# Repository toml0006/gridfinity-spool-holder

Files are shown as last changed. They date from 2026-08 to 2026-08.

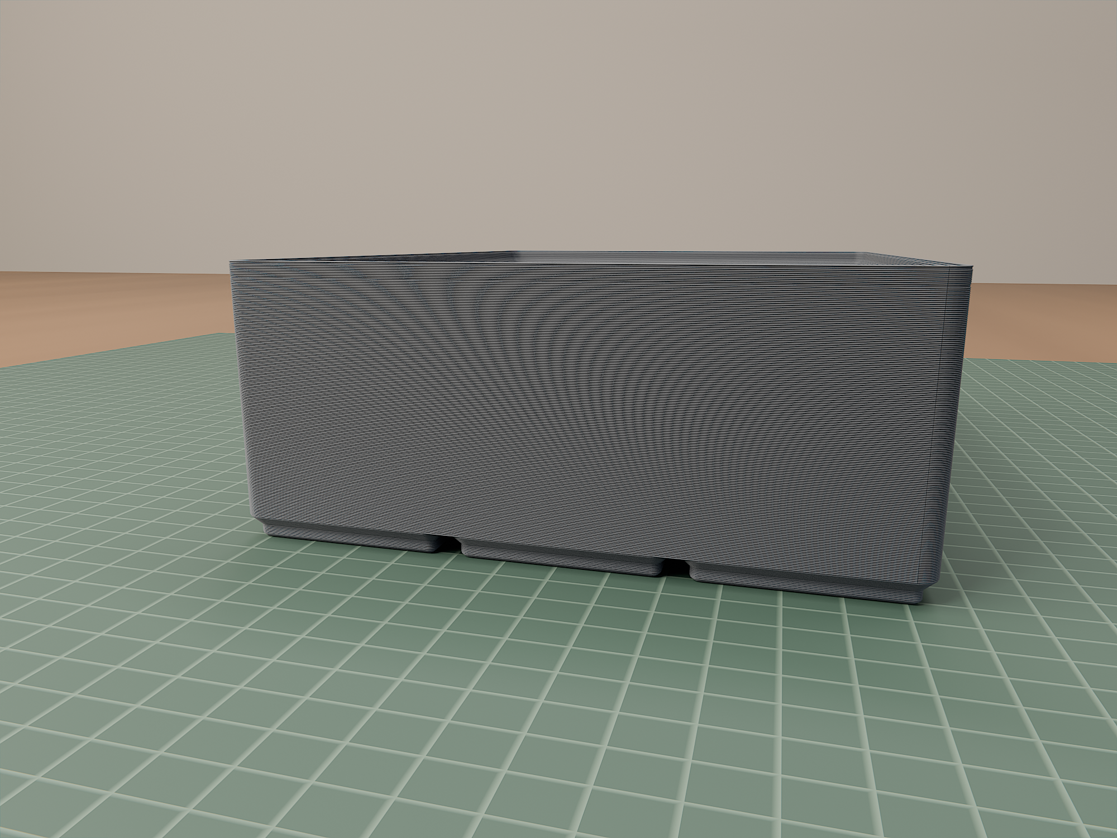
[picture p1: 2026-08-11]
renders/material_detail.png

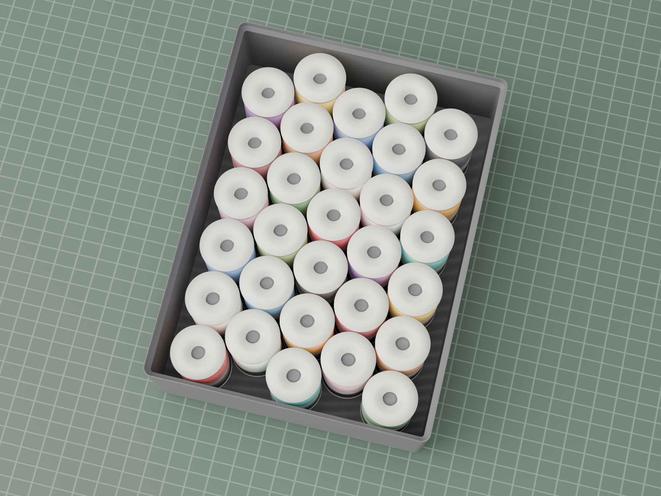
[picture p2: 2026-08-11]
renders/topdown_loaded.png

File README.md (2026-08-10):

# Gridfinity sewing thread spool holder

A stackable gridfinity bin with a hex-packed field of spool pegs.
3x4 cells, 7 height units, 30 spools.

```
make            # build the bin, validate it, build the test coupon
make bin        # out/spool_holder_3x4x7.stl
make coupon     # out/coupon_1x1.stl -- print this first
make validate   # measure the export against the spec
```

| | |
|---|---|
| Footprint | 125.5 x 167.5 mm (3 x 4 cells) |
| Height | 53.4 mm (7 units + 4.4 lip) |
| Stack pitch | 49.00 mm, exactly 7 per unit |
| Spools | 30 |
| Peg | dia 6.0, 38 mm proud of the floor, 0.75 chamfer |
| Modelled volume | 183 cm3 |

## Print the coupon first

`out/coupon_1x1.stl` is a 1x1 bin with a single peg, about ten minutes of
printing. It checks the three things that would otherwise waste a six hour
print: that the base seats in your baseplate, that the lip accepts another
bin, and that your spools actually fit the peg and the 24.68 mm spacing.

The lip is the one dimension not measured from a known-good local part --
see below -- so it is the thing most worth checking on a coupon.

## Where the numbers came from

Nothing here is recalled from memory. The base profile was measured off
`~/Documents/TomlinsonLTD/MakerWorld/Gridfinity/Calipers.3mf`, a bin known to
fit, by slicing it and fitting the geometry:

| Constant | Measured | How |
|---|---|---|
| Grid pitch | 42.0 | footprint / cell count |
| Outer footprint | 42n - 0.5 | 83.5 at 2 cells, 125.5 at 3 |
| Bottom inset | 3.20 / side | bottom span 77.60 at 2 cells |
| Chamfer angle | 45 deg | width grew 1.996 mm per mm |
| Base height | 4.75 | 0.8 + 1.8 + 2.15 |
| Corner radius | 3.75 top, 0.80 bottom | circle fit, error 0.0000 |
| Height convention | 7u + 3.8 lipless | 24.8 / 31.8 / 38.8 across 10 bins |

Cross-checked against `kennetek/gridfinity-rebuilt-openscad`, which agrees on
every one. Its `BASE_PROFILE_HEIGHT` reads 4.95, but its own segment lengths
(0.8 + 1.8 + 2.15) sum to 4.75 and the measured part is 4.75, so 4.75 is used.

### The lip is the unverified part

All ten local bins are lipless -- their outer wall runs dead straight from
the top of the base to the rim, so they seat in a baseplate but do not stack.
That left no local part to measure a stacking lip from, so the lip profile
(0.7 / 1.8 / 1.9, 4.4 tall) comes from the reference implementation only.

The rim inset is *derived* rather than taken: the bin above sinks until its
base flare jams against the rim, and that sink depth is the stack pitch.
Solving for a sink of exactly 4.4 gives a rim inset of 0.35, which puts the
pitch at exactly 49.00 mm for a 7 unit bin. `validate.py` recomputes this
from the exported mesh rather than trusting the constant.

## Peg layout

Derived from "2 large efficient Sewing Thread Spool Holder", measured off its
STLs: 23 pegs, dia 6.0, 38 mm proud of a 2 mm plate, chamfered tips, on a
lattice whose closest centre distance is 24.68 mm.

That 24.68 is the real constraint -- it is the widest a spool flange can be.
The original also spaced in-row neighbours 37.5 mm apart, which nothing
requires, so it spends 642 mm2 per spool where a true hex pack at the same
24.68 spacing spends 528. This model re-packs it properly: same clearances,
same spool compatibility, 30 spools instead of the 27 the original lattice
would tile into this footprint.

Columns run along Y. Running them the other way packs only 28.

## MakerWorld

`makerworld/gridfinity_spool_holder.scad` is a single self-contained file for
MakerWorld's Parametric Model Maker -- no `include<>` to resolve, and every
knob annotated for the customizer UI.

| Group | Parameters |
|---|---|
| Bin size | `grid_x`, `grid_y` (1-6 units), `grid_z` (3-20), `stacking_lip` |
| Spools | `spool_spacing`, `peg_dia`, `peg_height` |
| Shell | `wall`, `floor_thickness` |
| Quality | `detail` |

Footprint is capped at 6 units because 6 x 42 - 0.5 = 251.5mm, about as much
as a 256mm bed takes. `detail` is the escape hatch if generation times out:
it is facets per circle, and render time is close to linear in it.

Rendered locally on OpenSCAD 2021.01, which is CGAL only. Anything newer uses
the Manifold backend and is far quicker, so treat these as a pessimistic
ceiling rather than what MakerWorld will do:

| Case | Pegs | Render |
|---|---|---|
| 1x1x3 | 1 | 8s |
| 2x3x7 | 12 | 17s |
| 3x4x7 default | 30 | 25s |
| spacing 15 | 90 | 82s |
| 6x6x7 | 105 | 104s |

Every one of eleven cases across the parameter range -- the extremes of each
range, lipless, dense and sparse spacing, fat pegs, thick walls -- renders to
a watertight single body with positive volume. The default configuration also
passes all 33 geometry checks in `validate.py`.

Two things worth knowing if you edit it. Sections of the base and lip meet on
exact planes, and solids that only touch on a coincident face are not
reliably fused -- the result measures perfectly and is not watertight, so it
will not slice. The straight sections are deliberately grown 0.01mm into
their neighbours to prevent that. And rounded boxes are built as a hull of
four cylinders rather than `offset()` on a square: both are exact, but
`offset()` is a 2D minkowski and costs far more.

## Fusion 360

`fusion/GridfinitySpoolHolder.py` builds the same bin through the Fusion API.
Install it under `API/Scripts/GridfinitySpoolHolder/` and run it from
Utilities > Scripts and Add-Ins.

It opens a dialog first, seeded from the design's user parameters if they
exist and from the defaults in the file otherwise. Nothing is built and
nothing is deleted until you press OK. Pressing OK writes the values back to
the design, so the file, the dialog and the parameters stay in step. Set
`ASK_BEFORE_RUN = False` to skip the dialog for scripted runs.

**Changing a parameter does not rebuild the model on its own -- run the
script again.** That is a genuine limit rather than an oversight: the unit
counts and the spool spacing change how many feet and pegs exist, and a
parameter cannot add or remove bodies. Re-running is safe and repeatable,
because the script deletes the previous build first.

Deleting that previous build is fiddly enough to be worth recording. Deleting
the sketches does *not* cascade to the features that consumed them, and
calling `deleteMe()` on a body returns `True` while leaving the body in
place. Clearing anything other than the features first appears to work and
silently leaves the old bin behind, renamed to `Body2`, sitting inside the
new one. The features have to go first, newest to oldest.

| Parameter | Meaning |
|---|---|
| `gf_units_x` / `gf_units_y` | footprint, in 42mm gridfinity units |
| `gf_units_z` | height, in 7mm units |
| `spool_spacing` | peg centre spacing, and the widest flange that fits |
| `peg_height` / `peg_dia` | peg size |
| `wall` / `floor_thickness` | shell |

Peg count follows from the footprint and spacing; the lattice re-packs and
re-centres itself. Below 7 height units a 38mm peg stands proud of the rim
and the bin stops stacking, so the script warns and tells you the minimum.

The whole part is 11 features. Every peg circle shares one sketch and the
whole collection of profiles goes into a single extrude, and the base is one
foot plus a rectangular pattern. Extruding each profile separately instead
built the identical part out of 165 features and a 219 entry timeline.

## Known tradeoffs

- The base feet are modelled solid. Real gridfinity libraries hollow them to
  save material; here the slicer's infill does that job. If you want the
  filament back, hollowing the feet is the place to look.
- Wall is 1.6 mm, thicker than the 0.95 the reference uses, because the peg
  field puts spool loads on the walls.
- No label tab, no scoop. The pegs need the floor area more.

## Files

- `gridfinity.scad` -- base profile, stacking lip, bin shell. No spool logic,
  reusable for the next bin.
- `spool_holder.scad` -- peg lattice and assembly. Parameters at the top.
- `validate.py` -- measures an exported STL against the spec. 33 checks.

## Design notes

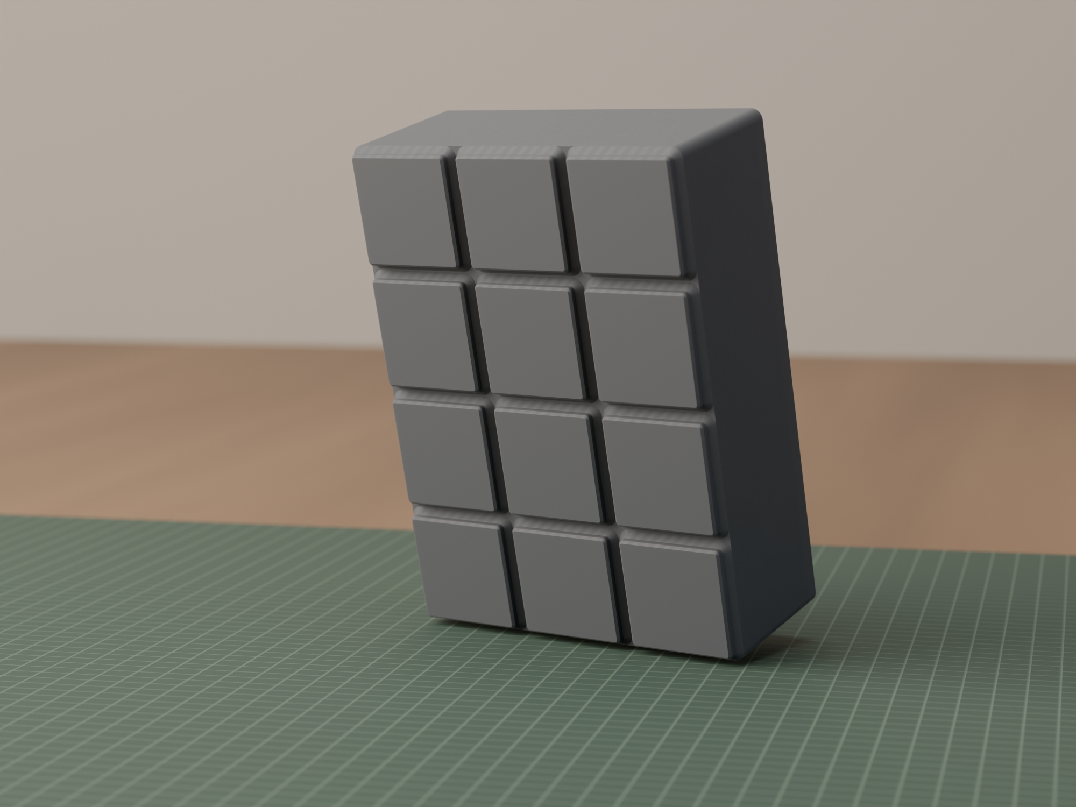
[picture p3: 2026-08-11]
renders/macro_base_lip.png

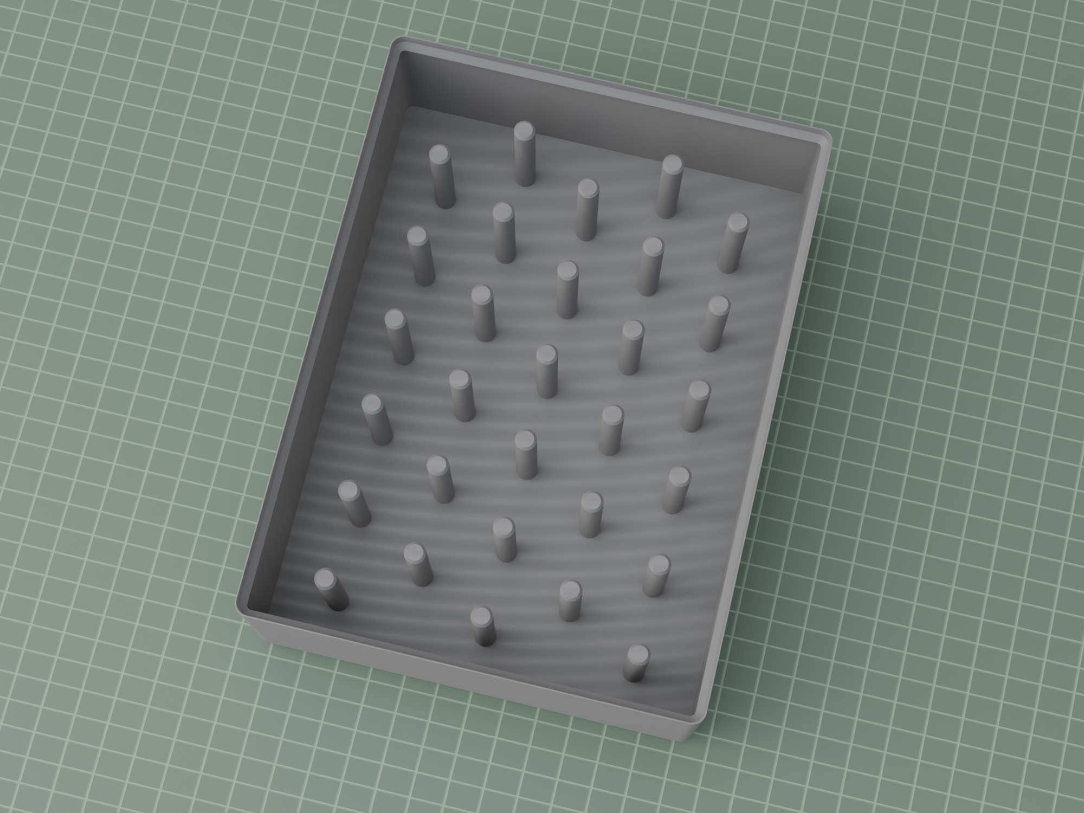
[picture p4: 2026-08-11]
renders/topdown_empty.png

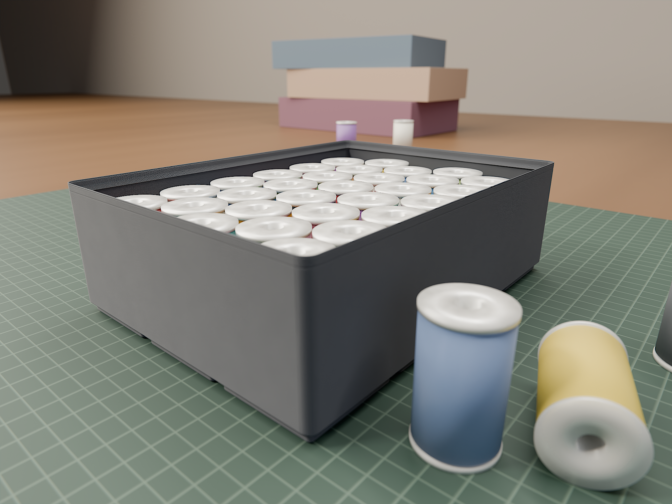
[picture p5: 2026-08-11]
renders/hero_loaded.png

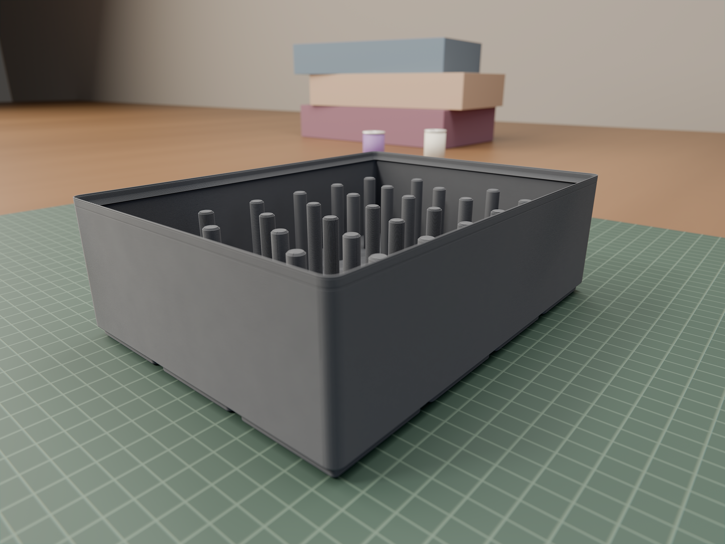
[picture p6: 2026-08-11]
renders/hero_empty.png

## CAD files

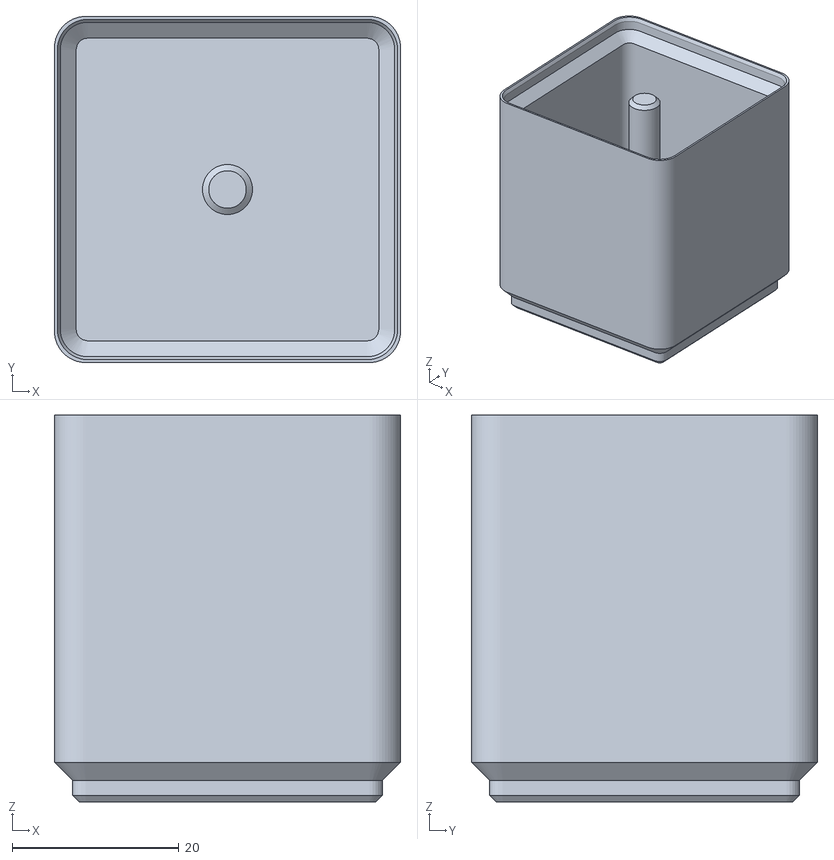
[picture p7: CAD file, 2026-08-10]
out/coupon_1x1.stl
41.5 x 41.5 x 46.4

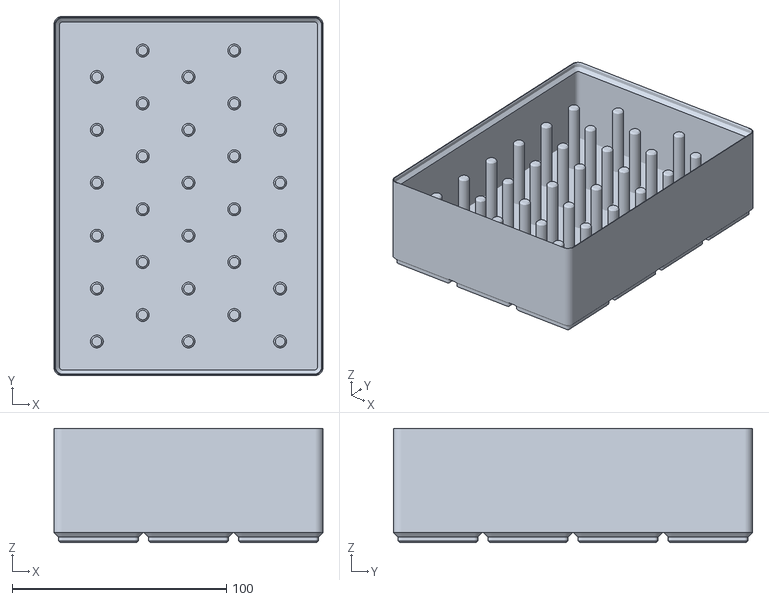
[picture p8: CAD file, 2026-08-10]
out/spool_holder_3x4x7.stl
125.5 x 167.5 x 53.4

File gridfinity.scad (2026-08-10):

// Gridfinity primitives.
//
// Every constant below was measured off a known-good bin
// (Documents/TomlinsonLTD/MakerWorld/Gridfinity/Calipers.3mf) rather than
// recalled, then cross-checked against kennetek/gridfinity-rebuilt-openscad.
// See README.md for the measurements and the one place the two disagree.

GF_PITCH      = 42;     // grid pitch
GF_GAP        = 0.5;    // outer footprint is PITCH*n - GAP
GF_TOP_INSET  = 0.25;   // = GAP/2, inset per side at top of base
GF_R_TOP      = 3.75;   // corner radius at top of base and up the wall

// Base profile, bottom to top. Insets are per side, measured in from the
// nominal 42mm cell edge. Bottom inset 3.20 = 0.25 + 0.8 + 2.15.
GF_BASE_C1    = 0.8;    // lower 45 deg chamfer
GF_BASE_STR   = 1.8;    // vertical section
GF_BASE_C2    = 2.15;   // upper 45 deg chamfer
GF_BASE_H     = GF_BASE_C1 + GF_BASE_STR + GF_BASE_C2;   // 4.75
GF_BOT_INSET  = GF_TOP_INSET + GF_BASE_C1 + GF_BASE_C2;  // 3.20

// Stacking lip. Insets are per side, in from the outer wall.
//
// The lip is a funnel that opens towards the rim: widest at the top so the
// feet of the bin above can drop in, narrowing to an inward ledge at the
// bottom of the lip which is what actually takes the load. Build it the
// other way up and the wall cavity just swallows it.
GF_LIP_C1     = 0.7;    // 45 deg at the rim, and the throat inset
GF_LIP_STR    = 1.8;    // vertical throat
GF_LIP_C2     = 1.9;    // 45 deg down to the ledge
GF_LIP_H      = GF_LIP_C1 + GF_LIP_STR + GF_LIP_C2;      // 4.40
GF_LIP_W      = GF_LIP_C1 + GF_LIP_C2;                   // 2.60, ledge inset
// Spec puts the rim at zero inset, i.e. a knife edge. Back it off so the rim
// prints as a real surface -- but the amount is derived, not chosen. The bin
// above sinks until its base flare jams on the rim, and that sink depth sets
// the stack pitch. Make it jam at exactly GF_LIP_H and the pitch comes out at
// exactly GF_UNIT_Z per height unit, so a tall stack stays on the grid.
//
// So the rim inset is however much wider the outer wall is than the base at
// GF_LIP_H above its underside: 0.60 - 0.25 = 0.35.
function gf_base_inset(t) =
      t <= GF_BASE_C1               ? GF_BOT_INSET - t
    : t <= GF_BASE_C1 + GF_BASE_STR ? GF_BOT_INSET - GF_BASE_C1
    : max(GF_TOP_INSET, GF_BOT_INSET - GF_BASE_C1 - (t - GF_BASE_C1 - GF_BASE_STR));

GF_LIP_TIP    = gf_base_inset(GF_LIP_H) - GF_TOP_INSET;   // 0.35

GF_UNIT_Z     = 7;      // height unit
GF_Z_LIPLESS  = 3.8;    // total = 7*u + this, for a lipless bin

// Corner radius shrinks 1:1 with inset, so the whole base is one rounded
// rect swept through a varying offset. Falls out of the measurements:
// at inset 3.20 this gives 0.80, and 0.80 is what the bottom face measures.
function gf_radius(inset) = GF_R_TOP - (inset - GF_TOP_INSET);

function gf_outer(n) = GF_PITCH * n - GF_GAP;

// Total outer height of a bin.
function gf_height(zu, lip = true) =
    GF_UNIT_Z * zu + (lip ? GF_LIP_H : GF_Z_LIPLESS);

// Rounded rectangular prism, centered in X/Y, sitting on z=0.
module gf_rrect(sx, sy, r, h) {
    linear_extrude(height = h)
        offset(r = r)
            square([sx - 2*r, sy - 2*r], center = true);
}

// A rounded rect described by its inset from a footprint, so radius stays
// consistent with the profile.
module gf_rrect_inset(fx, fy, inset, h) {
    gf_rrect(fx - 2*inset, fy - 2*inset, gf_radius(inset), h);
}

// One base foot, occupying a single 42mm cell, sitting on z=0.
module gf_foot(eps = 0.002) {
    P = GF_PITCH;
    // 45 deg run-out from the bottom inset to the straight section
    hull() {
        gf_rrect_inset(P, P, GF_BOT_INSET, eps);
        translate([0, 0, GF_BASE_C1 - eps])
            gf_rrect_inset(P, P, GF_BOT_INSET - GF_BASE_C1, eps);
    }
    // straight section
    translate([0, 0, GF_BASE_C1])
        gf_rrect_inset(P, P, GF_BOT_INSET - GF_BASE_C1, GF_BASE_STR);
    // 45 deg flare out to full width at the top of the base
    hull() {
        translate([0, 0, GF_BASE_C1 + GF_BASE_STR])
            gf_rrect_inset(P, P, GF_BOT_INSET - GF_BASE_C1, eps);
        translate([0, 0, GF_BASE_H - eps])
            gf_rrect_inset(P, P, GF_TOP_INSET, eps);
    }
}

// Full base: one foot per cell, arrayed on the grid. The 0.5mm grooves
// between adjacent feet are intentional and are what the grid looks like.
module gf_base(gx, gy) {
    for (i = [0:gx-1], j = [0:gy-1])
        translate([(i - (gx-1)/2) * GF_PITCH,
                   (j - (gy-1)/2) * GF_PITCH, 0])
            gf_foot();
}

// Solid outer body from the top of the base up to `h`.
module gf_body(gx, gy, h) {
    translate([0, 0, GF_BASE_H])
        gf_rrect(gf_outer(gx), gf_outer(gy), GF_R_TOP, h - GF_BASE_H);
}

// Negative for the stacking lip: the socket cut into the rim that receives
// the feet of the bin above. Cut from the ledge upward, widening as it goes.
module gf_lip_negative(gx, gy, h, eps = 0.002) {
    fx = gf_outer(gx);
    fy = gf_outer(gy);
    throat_z = h - GF_LIP_C1 - GF_LIP_STR;
    // ledge at the bottom of the lip, opening out to the throat
    hull() {
        translate([0, 0, h - GF_LIP_H])
            gf_rrect_inset(fx, fy, GF_LIP_W, eps);
        translate([0, 0, throat_z])
            gf_rrect_inset(fx, fy, GF_LIP_C1, eps);
    }
    // vertical throat
    translate([0, 0, throat_z])
        gf_rrect_inset(fx, fy, GF_LIP_C1, GF_LIP_STR);
    // final flare out to the rim
    hull() {
        translate([0, 0, h - GF_LIP_C1])
            gf_rrect_inset(fx, fy, GF_LIP_C1, eps);
        translate([0, 0, h - eps])
            gf_rrect_inset(fx, fy, GF_LIP_TIP, eps);
    }
    // everything above the rim is open
    translate([0, 0, h - eps])
        gf_rrect_inset(fx, fy, GF_LIP_TIP, GF_LIP_H);
}

// An open bin: base, walls, cavity, optional stacking lip.
// The cavity floor sits at z = GF_BASE_H + floor_h.
module gf_bin(gx, gy, zu, wall = 1.6, floor_h = 1.25, lip = true) {
    h = gf_height(zu, lip);
    difference() {
        union() {
            gf_base(gx, gy);
            gf_body(gx, gy, h);
        }
        // Interior cavity. It has to stop at the bottom of the lip, otherwise
        // it cuts straight through and erases the ledge -- the wall is
        // thinner than the ledge inset, so whichever cut runs deeper wins.
        cavity_top = lip ? h - GF_LIP_H : h;
        floor_z = GF_BASE_H + floor_h;
        translate([0, 0, floor_z])
            gf_rrect(gf_outer(gx) - 2*wall, gf_outer(gy) - 2*wall,
                     max(0.1, GF_R_TOP - wall), cavity_top - floor_z);
        if (lip) gf_lip_negative(gx, gy, h);
    }
}

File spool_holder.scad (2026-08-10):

// Gridfinity sewing thread spool holder.
//
// Derived from "2 large efficient Sewing Thread Spool Holder", whose peg
// geometry was measured directly off its STLs: 23 pegs, dia 6.0, 38mm proud
// of a 2mm plate, with a lead-in chamfer at the tip, on a lattice whose
// closest center-to-center distance is 24.68mm.
//
// That 24.68 is the real constraint -- it is the widest a spool flange can
// be. The original lattice also spaced in-row neighbours 37.5mm apart, which
// is pure slack, so this version re-packs the same spacing as a true hex
// grid. Same clearances, more spools.

include <gridfinity.scad>

/* [Grid] */
GRID_X       = 3;      // cells in X
GRID_Y       = 4;      // cells in Y
GRID_Z       = 7;      // height units (7mm each)
STACKING_LIP = true;   // false matches the rest of the library, but won't stack

/* [Shell] */
WALL         = 1.6;    // side wall thickness
FLOOR        = 1.25;   // floor above the top of the gridfinity base

/* [Spools] */
SPOOL_DIA    = 24.68;  // widest spool flange = min peg center distance
PEG_DIA      = 6.0;    // spool bore is ~6.3
PEG_H        = 38.0;   // proud of the floor
PEG_CHAMFER  = 0.75;   // lead-in at the tip

/* [Output] */
PART         = "bin";  // "bin" or "coupon"

$fa = 1;
$fs = 0.4;

// ---------------------------------------------------------------------------
// Peg lattice
//
// Columns run along Y so the long axis of the bin gets the tighter spacing.
// For a 3x4 that packs 30 pegs; running them the other way packs only 28.
// ---------------------------------------------------------------------------

function col_spacing() = SPOOL_DIA * sqrt(3) / 2;

// Usable span for peg *centers*: interior minus half a spool at each edge.
function span_x(gx) = gf_outer(gx) - 2*WALL - SPOOL_DIA;
function span_y(gy) = gf_outer(gy) - 2*WALL - SPOOL_DIA;

function n_cols(gx) = floor(span_x(gx) / col_spacing()) + 1;
function col_offset(j) = (j % 2 == 1) ? SPOOL_DIA/2 : 0;
function n_in_col(gy, j) = floor((span_y(gy) - col_offset(j)) / SPOOL_DIA) + 1;

function peg_grid(gx, gy) = [
    for (j = [0 : n_cols(gx) - 1], i = [0 : n_in_col(gy, j) - 1])
        [ j * col_spacing(), col_offset(j) + i * SPOOL_DIA ]
];

// Center the generated pattern in the interior rather than assuming it is
// symmetric -- offset columns end at a different Y than even ones.
function grid_extent(pts, axis) =
    max([for (p = pts) p[axis]]) - min([for (p = pts) p[axis]]);

module peg() {
    straight = PEG_H - PEG_CHAMFER;
    cylinder(h = straight, d = PEG_DIA);
    translate([0, 0, straight])
        cylinder(h = PEG_CHAMFER, d1 = PEG_DIA, d2 = PEG_DIA - 2*PEG_CHAMFER);
}

module peg_field(gx, gy) {
    pts = peg_grid(gx, gy);
    ox = -grid_extent(pts, 0) / 2;
    oy = -grid_extent(pts, 1) / 2;
    for (p = pts) translate([p[0] + ox, p[1] + oy, 0]) peg();
}

// ---------------------------------------------------------------------------
// Assembly
// ---------------------------------------------------------------------------

module spool_bin(gx, gy, zu) {
    union() {
        gf_bin(gx, gy, zu, WALL, FLOOR, STACKING_LIP);
        translate([0, 0, GF_BASE_H + FLOOR]) peg_field(gx, gy);
    }
}

// A 1x1 test print: checks baseplate fit, lip fit and spool fit for the cost
// of a few minutes, before committing to the full bin.
module coupon() {
    union() {
        gf_bin(1, 1, 6, WALL, FLOOR, STACKING_LIP);
        translate([0, 0, GF_BASE_H + FLOOR]) peg();
    }
}

if (PART == "coupon") coupon();
else spool_bin(GRID_X, GRID_Y, GRID_Z);

echo(str("pegs = ", len(peg_grid(GRID_X, GRID_Y))));
echo(str("outer = ", gf_outer(GRID_X), " x ", gf_outer(GRID_Y),
         " x ", gf_height(GRID_Z, STACKING_LIP)));

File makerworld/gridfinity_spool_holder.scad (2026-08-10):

/*
 * Gridfinity sewing thread spool holder -- parametric.
 *
 * A stackable gridfinity bin whose floor is a hex packed field of pegs, one
 * spool per peg. Set the footprint in gridfinity units and the spacing to
 * suit your spools; the peg field re-packs and re-centres itself.
 *
 * Single file on purpose: MakerWorld's Parametric Model Maker runs one
 * script, so there are no include<> statements to resolve.
 *
 * Every gridfinity constant here was measured off a bin known to fit rather
 * than recalled. Source and validator:
 * https://github.com/toml0006/gridfinity-spool-holder
 */

/* [Bin size] */

// Width, in gridfinity units of 42mm. 6 units is 251.5mm, about as much as a 256mm bed takes
grid_x = 3;         // [1:6]
// Depth, in gridfinity units of 42mm
grid_y = 4;         // [1:6]
// Height, in units of 7mm. Below 7 a 38mm peg stands proud of the rim and the bin stops stacking
grid_z = 7;         // [3:20]
// Stacking lip. Turn off to match a lipless library: still seats in a baseplate, but will not stack
stacking_lip = true;

/* [Spools] */

// Centre to centre spacing. This is the widest spool flange that will fit
spool_spacing = 24.68;  // [15:0.01:60]
// Peg diameter. Typical spool bore is about 6.3mm
peg_dia = 6;        // [3:0.1:12]
// How far the peg stands above the floor
peg_height = 38;    // [10:1:80]

/* [Shell] */

// Side wall thickness
wall = 1.6;         // [0.8:0.1:4]
// Floor above the top of the gridfinity base
floor_thickness = 1.25;  // [0.8:0.05:4]

/* [Quality] */

// Facets per full circle. Raise for a smoother finish, lower if generating times out
detail = 20;        // [12:4:48]

/* [Hidden] */

// --------------------------------------------------------------------------
// Gridfinity constants. Measured, not tuned.
//
//   pitch 42, outer footprint 42n - 0.5, corner radius 3.75 at the top of the
//   base falling to 0.80 at the bottom face, base profile 0.8 chamfer / 1.8
//   straight / 2.15 chamfer = 4.75 tall, both chamfers at 45 degrees.
// --------------------------------------------------------------------------

PITCH      = 42;
GAP        = 0.5;
TOP_INSET  = GAP / 2;                       // 0.25
R_TOP      = 3.75;

BASE_C1    = 0.8;                           // lower 45 deg chamfer
BASE_STR   = 1.8;                           // vertical section
BASE_C2    = 2.15;                          // upper 45 deg chamfer
BASE_H     = BASE_C1 + BASE_STR + BASE_C2;  // 4.75
BOT_INSET  = TOP_INSET + BASE_C1 + BASE_C2; // 3.20

UNIT_Z     = 7;
Z_LIPLESS  = 3.8;

// Stacking lip: a funnel that opens towards the rim. Widest at the top so the
// feet of the bin above drop in, narrowing to an inward ledge at the bottom
// which is what takes the load. Built the other way up, the wall cavity just
// swallows it and there is no lip at all.
LIP_C1     = 0.7;                           // throat inset, and the rim chamfer
LIP_STR    = 1.8;                           // vertical throat
LIP_C2     = 1.9;                           // 45 deg down to the ledge
LIP_H      = LIP_C1 + LIP_STR + LIP_C2;     // 4.40
LIP_W      = LIP_C1 + LIP_C2;               // 2.60, ledge inset

PEG_CHAMFER = 0.75;                         // lead-in at the peg tip
EPS         = 0.01;

// Sections of the base and the lip meet on exact planes. Solids that only
// touch on a coincident face are not reliably fused, and the result is a
// shell that measures correctly but is not watertight, so it will not slice.
// Straight sections are grown by this much into their neighbours to give the
// union real volume to work with. It is below one print layer.
OVER = 0.01;

// Inset per side of a base, t mm above its underside.
function base_inset(t) =
      t <= BASE_C1             ? BOT_INSET - t
    : t <= BASE_C1 + BASE_STR  ? BOT_INSET - BASE_C1
    : max(TOP_INSET, BOT_INSET - BASE_C1 - (t - BASE_C1 - BASE_STR));

// The bin above sinks until its base flare jams on the rim, and that depth is
// the stack pitch. Seating at exactly LIP_H makes the pitch exactly UNIT_Z per
// height unit, which is what keeps a tall stack on the grid.
LIP_TIP = base_inset(LIP_H) - TOP_INSET;    // 0.35

function outer(n)  = PITCH * n - GAP;
function radius_for(inset) = max(0.01, R_TOP - (inset - TOP_INSET));
function total_height() = UNIT_Z * grid_z + (stacking_lip ? LIP_H : Z_LIPLESS);

// --------------------------------------------------------------------------
// Primitives
//
// Rounded boxes are built as a hull of four cylinders rather than
// offset() on a square. Both are exact, but offset() is a 2D minkowski and
// costs far more; on a 3x4 bin the cylinder form renders many times faster,
// which matters when the generator has a wall-clock budget.
// --------------------------------------------------------------------------

module rbox(sx, sy, r, h) {
    rr = max(0.01, min(r, min(sx, sy) / 2 - 0.001));
    hull()
        for (dx = [-1, 1], dy = [-1, 1])
            translate([dx * (sx / 2 - rr), dy * (sy / 2 - rr), 0])
                cylinder(h = max(h, EPS), r = rr, $fn = detail);
}

// Rounded box described by its inset from a footprint, so the corner radius
// stays consistent with the base profile.
module rbox_inset(fx, fy, inset, h) {
    rbox(fx - 2 * inset, fy - 2 * inset, radius_for(inset), h);
}

// A 45 degree run between two insets, as a single hull of eight cylinders.
module taper(fx, fy, z0, inset0, z1, inset1) {
    hull() {
        translate([0, 0, z0]) rbox_inset(fx, fy, inset0, EPS);
        translate([0, 0, z1 - EPS]) rbox_inset(fx, fy, inset1, EPS);
    }
}

// --------------------------------------------------------------------------
// Base
// --------------------------------------------------------------------------

// One foot, occupying a single 42mm cell.
module foot() {
    taper(PITCH, PITCH, 0, BOT_INSET, BASE_C1, BOT_INSET - BASE_C1);
    translate([0, 0, BASE_C1 - OVER])
        rbox_inset(PITCH, PITCH, BOT_INSET - BASE_C1, BASE_STR + 2 * OVER);
    taper(PITCH, PITCH, BASE_C1 + BASE_STR, BOT_INSET - BASE_C1,
          BASE_H, TOP_INSET);
}

// The 0.5mm grooves between adjacent feet are intentional; that is what the
// underside of a gridfinity bin looks like.
module base() {
    for (i = [0 : grid_x - 1], j = [0 : grid_y - 1])
        translate([(i - (grid_x - 1) / 2) * PITCH,
                   (j - (grid_y - 1) / 2) * PITCH, 0])
            foot();
}

// --------------------------------------------------------------------------
// Peg lattice
// --------------------------------------------------------------------------

// Hex packed with columns running along Y. The spacing is the only real
// constraint: it is the widest a spool flange can be. Columns along Y pack 30
// pegs into a 3x4; running them the other way packs only 28.
function col_spacing() = spool_spacing * sqrt(3) / 2;
function span_x() = outer(grid_x) - 2 * wall - spool_spacing;
function span_y() = outer(grid_y) - 2 * wall - spool_spacing;
function n_cols()  = span_x() < 0 ? 0 : floor(span_x() / col_spacing()) + 1;
function col_off(j) = (j % 2 == 1) ? spool_spacing / 2 : 0;
function n_in_col(j) = span_y() < col_off(j) ? 0
                     : floor((span_y() - col_off(j)) / spool_spacing) + 1;

function peg_grid() = [
    for (j = [0 : max(0, n_cols() - 1)], i = [0 : max(0, n_in_col(j) - 1)])
        if (n_cols() > 0 && n_in_col(j) > 0)
            [j * col_spacing(), col_off(j) + i * spool_spacing]
];

// Offset columns end at a different Y than even ones, so the generated block
// is not symmetric about its own origin and has to be centred explicitly.
function grid_mid(pts, axis) =
    (min([for (p = pts) p[axis]]) + max([for (p = pts) p[axis]])) / 2;

// Revolved as one solid rather than a shaft plus a cone. Two primitives per
// peg means twice the solids for the final union to chew through, and with
// thirty pegs that is the single biggest cost in the script.
module peg() {
    r = peg_dia / 2;
    r_tip = max(0.05, r - PEG_CHAMFER);
    straight = peg_height - PEG_CHAMFER;
    // Sunk OVER into the floor for the same reason the base sections overlap.
    rotate_extrude($fn = detail)
        polygon([[0, -OVER], [r, -OVER], [r, straight],
                 [r_tip, peg_height], [0, peg_height]]);
}

module peg_field() {
    pts = peg_grid();
    if (len(pts) > 0) {
        ox = grid_mid(pts, 0);
        oy = grid_mid(pts, 1);
        for (p = pts) translate([p[0] - ox, p[1] - oy, 0]) peg();
    }
}

// --------------------------------------------------------------------------
// Assembly
// --------------------------------------------------------------------------

module lip_negative(fx, fy, h) {
    throat_z = h - LIP_C1 - LIP_STR;
    taper(fx, fy, h - LIP_H, LIP_W, throat_z, LIP_C1);
    translate([0, 0, throat_z - OVER])
        rbox_inset(fx, fy, LIP_C1, LIP_STR + 2 * OVER);
    taper(fx, fy, h - LIP_C1, LIP_C1, h, LIP_TIP);
    translate([0, 0, h - EPS]) rbox_inset(fx, fy, LIP_TIP, LIP_H);
}
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

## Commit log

2026-08-10 Add gridfinity spool holder, 3x4x7 with 30 hex-packed pegs
    Regenerates the "2 large efficient Sewing Thread Spool Holder" as a native
    gridfinity bin rather than wrapping the original 100x150 print in a sleeve.
    The base profile is measured off a known-good local bin (Calipers.3mf) rather
    than recalled: 42 pitch, 42n-0.5 footprint, 0.8/1.8/2.15 base at 45 degrees,
    3.75 corner radius. Cross-checked against gridfinity-rebuilt-openscad, which
    agrees on every constant.
    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
    [coupon_1x1.stl, gridfinity.scad, spool_holder.scad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]
2026-08-10 Add Fusion 360 script, verified against the same 33 checks
    Generates the same bin through the Fusion API instead of OpenSCAD, driven by
    gridfinity unit counts for width, depth and height plus spool spacing and peg
    height. Mirrors the inputs into user parameters so they are visible in the UI.
    Built in a live Fusion session over the local MCP server, exported to STL and
    run through validate.py: 33/33, identical numbers to the OpenSCAD build, and
    volume agrees to 182.99 vs 182.9 cm3. Two independent implementations landing
    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
2026-08-10 Make the Fusion parameters actually drive the model
    The user parameters were decorative. Every extrude distance was a literal and
    every sketch had zero dimensions and zero constraints, so nothing in 175
    timeline features referenced a parameter -- editing gf_units_x to 2 left a
    125.5mm body on screen.
    The script now reads the parameters back out of the design and rebuilds, so
    editing them in Modify > Change Parameters and re-running produces the right
    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
2026-08-10 Prompt before building, and cut 165 features down to 11
    Two problems, both mine.
    The script built and deleted immediately on launch. It now opens a dialog
    seeded from the design parameters, so nothing is touched until you press OK,
    and the values you set are written back to the design. ASK_BEFORE_RUN = False
    skips it for scripted runs.
    The operations were also unbatched to the point of absurdity: every peg got
    its own extrude and every foot got three, so a part that needs about a dozen
    features was built from 165 with a 219 entry timeline. Every peg circle now
    shares one sketch and the whole profile collection goes into a single
    extrude, and the base is one foot plus a rectangular pattern.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
2026-08-10 Add a single-file parametric model for MakerWorld
    MakerWorld's Parametric Model Maker runs one script, so gridfinity.scad and
    spool_holder.scad are inlined into makerworld/gridfinity_spool_holder.scad
    with customizer annotations on every parameter.
    Footprint is capped at 6 units because 6*42-0.5 is 251.5mm, about as much as
    a 256mm bed takes, and detail is exposed as the escape hatch if generation
    times out.
    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
    [gridfinity_spool_holder.scad]
2026-08-10 Add studio renders and the script that produces them
    Six shots for a model listing: hero empty and loaded, a stacked pair, the peg
    field from above empty and loaded, and the underside showing the gridfinity
    feet.
    Scenes are assembled at 1 unit = 1 metre and lit in watts, so falloff, shadow
    softness and depth of field fall out of physical numbers. That also means the
    light values look surprisingly small: the first pass used 900W softboxes and
    blew a 0.055 albedo to near white.
    Spools are generated rather than modelled, revolved from a profile at the
    dimensions the 24.68mm peg spacing permits, so what sits in the bin is what
    actually fits. The stacked shot separates the bins by exactly 49.00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
2026-08-11 Fix parts sinking into the ground, and move the renders to a craft room
    The bin's underside sits at exactly z=0 and so did the table, and two
    coplanar faces z-fight: the renderer let the ground cut through the feet, so
    every shot had the part sunk into the floor. Anything resting on a surface is
    now lifted 0.15mm, which is sub-visible and enough. Verified by measuring the
    imported mesh rather than by eye, which is how it got shipped the first time.
    The filament shader was one texture applied everywhere. A print shows layer
    lines on its walls and extrusion beads on its top faces, at different pitches
    and directions, and using layer lines on a top surface is most of what made
    this read as CAD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
2026-08-11 Fix the filament shader: texture space was 1000x off
    The layer lines never worked, and lighting and profile tuning were never
    going to fix it. stl_import(global_scale) sets object.scale and leaves the
    mesh in millimetres, but object-space texture coordinates read mesh-local
    values. The shader was seeing a part 53 units tall instead of 0.053, so a
    pitch computed from the real 0.2mm layer height asked for a period of
    0.0002mm and aliased into noise. That was the corduroy on the corner shot and
    the flat grey head on. Scale is now applied at import so local space is
    metres like everything else.
    With the space right, the profile matters. A bead is not a sine wave: it
    leaves the nozzle round, get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
2026-08-11 Rework the filament shader on external research
    Asked Codex (gpt-5.6-sol, high effort) to research state of the art FDM
    rendering. Its diagnosis: the shader over-describes layer relief and
    under-describes the manufacturing path, and a perfectly periodic arc repeated
    every 0.20mm with matching roughness and AO is almost exactly how you get "CG
    plastic with stripes".
    Applied, in its priority order:
    Decorrelated the signals. Displacement, roughness and base colour were all
    driven by the same layer waveform, so every layer got an identical bright
    crest and black groove. Now the layer envelope drives displacement only, a
    45um noise drives bump only, a 7mm noise drives roughness only, and nothin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
2026-08-11 Re-render hero with the reworked filament shader
    Claude-Session: https://claude.ai/code/session_01Jk8rMwnMvfnDQXcvgpwSRv
2026-08-11 Make layer lines actually visible at listing framing
    The physically measured 45um envelope is correct and invisible. Bump shades
    weaker than displacement, the Cycles denoiser eats 2-3px detail, and the 1.5m
    window is soft enough to shade micro relief almost not at all -- so the hero
    came back looking like smooth injection moulded plastic.
    Raised the bump envelope to 190um for the non-displaced path and added a
    small harder accent raking down the front walls. That is above the measured
    surface roughness and I am choosing it deliberately: a listing image has to
    show the part is printed, and nobody buying a model cares that the relief is
    4x the true Ra.
    The material_detail shot keeps real dis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
2026-08-11 Emulate a 0.28mm draft print instead of 0.2mm
    Coarser pitch separates the lines and makes them read better at listing
    framing: 191 layers up the 53.4mm wall instead of 267.
    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
2026-08-11 Cross-wound thread, iPhone camera emulation, spool iteration shot
    Asked Codex to research photorealistic thread spools. Its structural
    correction: a domestic polyester spool is traverse wound into a cross-wound
    package. The guide reciprocates along the axis while the spool turns, so one
    traverse lays a right-handed helix and the return lays a left-handed one.
    It is not a stack of rings, and not one continuous helix -- which is what my
    bands-around-Z wave was, and why the thread read as a dyed plastic cylinder.
    Implemented its top three priorities:
    Two opposed helix families at 12 degrees from circumferential (24 degree
    included crossing angle, within the 10-18 practical range), phase compu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
2026-08-11 Re-render hero: the previous one predated the set, framing and thread fixes
    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
2026-08-11 Deepen focus, strengthen layer lines and thread relief
    Three complaints, three causes.
    Depth of field: f/1.78 is the phone's real aperture, but at the 190mm working
    distance the 24mm-equivalent lens needs to sit at, that is macro range and
    millimetres deep. Stopped down to f/8 so the subject is sharp front to back.
    Layer lines: raised to 320um. The measured envelope is 45um and the framing,
    denoiser and compositor sharpening between them erase anything near it.
    Thread: the apparent yarn diameter is 0.18-0.25mm for Tex 27-30, which puts a
    single strand near one pixel at this framing -- invisible. Coarsened to 0.30mm
    and tripled the relief so the cross-wind actually reads.
    Also lifted the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
2026-08-11 Model thread as twisted cord in horizontal wraps, and ease the focus back
    The cross-wind was structurally right and looked wrong: two crossing families
    of equal weight read as woven fabric, not as thread. What a spool actually
    shows is a plied cord laid down in near-horizontal wraps, which is two scales
    rather than one crossing pattern:
    wrap -- horizontal bands, one per strand, straight off Z at 0.30mm
    twist -- ply grooves spiralling along each strand, 0.24mm at 34 degrees
    The twist multiplies the wrap instead of adding to it, so each strand stays a
    single rounded cord with a spiral groove cut into it rather than becoming two
    crossing ribs. Anisotropy now follows the circumferential d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
2026-08-11 Build the bin from real sliced toolpaths instead of shading a CAD shell
    Every shader approach was approximating a print. This slices the STL with
    PrusaSlicer and builds the actual extrusion paths as geometry, so the layer
    stepping, the seam, the contour rings on top surfaces and the scalloped
    silhouette are all real shape. The material is then just plastic -- a rough
    dielectric over pigment -- and the geometry does the lighting.
    191 layers, 302k extrusion moves, 4807 continuous beads, about 2.4M verts.
    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
2026-08-11 Supersample the render, and fuse the beads further
    The moire and the missing layer definition were one problem. A 0.28mm layer
    projects to 2-3px at listing framing, right at Nyquist: point sampled it
    either averages to flat grey or beats against the pixel grid. Rendering at 2x
    and box filtering down gives each delivered pixel the real sub-pixel bead
    detail, which fixes both at once. Nothing else could: raising contrast makes
    the aliasing worse, and lowering it erases the layers.
    Also widened the bead to 16 percent over the layer pitch so neighbours fuse
    properly -- the gaps between beads were reading far darker than a real print,
    which was the high contrast between layer and gap -- and took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
2026-08-11 Ground the plastic in a real environment and break up its roughness
    Researched PLA values: IOR 1.46 (PLA is 1.448-1.5), metallic 0, matte
    roughness in the 0.6-0.9 band, and essentially no subsurface since PLA has
    none of acrylic's translucency.
    The bigger miss was environmental. The world was a flat colour, so every
    reflection on the plastic was a featureless wash -- which is most of why a
    shader with correct values still reads as CG. Swapped in a procedural Nishita
    sky so reflections have a gradient and a sun to catch.
    Roughness now runs 0.62-0.80 driven by two noise scales rather than one, on
    the principle that no real surface has uniform roughness.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
2026-08-11 Attack the moire at the source: filter width, box downsample, no sharpening
    Moire cannot be removed in post -- once the sampling has aliased, the false
    low frequency is indistinguishable from real detail at that frequency, and
    blurring it also destroys the layer lines. It has to be pre-filtered.
    Three levers, one of which was a genuine mistake:
    Cycles' pixel filter defaults to 1.5px and I never touched it. Widened to
    2.2, so each pixel integrates a larger neighbourhood of sub-pixel samples.
    The downsample claimed to box filter and did not -- Image.scale() resamples
    with a cheap kernel that skips most sub-pixel samples, throwing away much of
    the point of rendering at 3x. Now averages the e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
2026-08-11 Render with source-level anti-aliasing: moire resolved
    Pixel filter 2.2, true box downsample in linear light, sharpening off. The
    peg cylinders now show distinct layer bands instead of shimmering, which no
    amount of shader work had been able to fix.
    Two side effects worth noting: averaging in linear light lifts the midtones
    compared to the naive scale it replaced, so the part reads lighter than the
    0.05 albedo suggests; and the float buffer saves as 16-bit PNG, hence the
    file being 12MB rather than 3.5MB.
    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
2026-08-11 Give the sky to glossy rays only
    Measured off the render: the front wall sat at 0.71 sRGB where a 0.05 albedo
    part lit normally belongs near 0.24, and the dark green mat at 0.76. About
    nine times too much light in linear terms.
    A Nishita sky is a full hemisphere at physical radiance, so even 0.09 was
    dominating the softboxes. Splitting by ray type lets glossy rays reflect a
    bright sky while diffuse rays see 0.006, which keeps the reflection grounding
    without the sky lighting the scene.
    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
2026-08-11 Dirty the thread
    Dust settles in the grooves between wraps, where nothing wipes it away, so
    the dirt is driven by ambient occlusion rather than noise -- it lands where
    the geometry actually traps it, darker and desaturated at 0.42 of the dyed
    colour. Plus loose fibre finer than the ply grooves, and a broad roughness
    drift so dust kills the sheen unevenly instead of flatly.
    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
2026-08-11 Pick the GPU backend by probing, not by hardcoding METAL
    The 3090 rendered at 0% GPU utilisation because the device selection set
    compute_device_type to METAL unconditionally: on an NVIDIA machine that
    raises, the except branch set CPU, and Cycles quietly ground away on cores
    while a 24GB card sat idle.
    Now probes OPTIX, CUDA, METAL, HIP, ONEAPI in order and only enables devices
    of the backend that took. OPTIX before CUDA because it uses the RT cores,
    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
2026-08-11 Render the full set on the RTX 3090 via OptiX
    All eight shots in 25m20s, about three minutes each. The M1 Max needed
    roughly twenty minutes for one shot at the same settings.
    Confirmed OPTIX from the log rather than assuming it. Early nvidia-smi polls
    showed 0% five times running, which looked like proof it had fallen back to
    CPU; the tell was CPU accumulation of 112 seconds over 3.5 minutes, about
    half a core, far too low for CPU path tracing. Cycles spends its opening
    minutes converting 4807 curve splines to 2.4M verts single threaded with the
    GPU idle, so early utilisation polls mean nothing.
    Rendered on Blender 4.3.2 against 4.2.2 on the Macs, so this set is
    internally consistent but n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
